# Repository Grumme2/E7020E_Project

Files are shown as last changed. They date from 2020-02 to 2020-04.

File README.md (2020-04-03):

# E7020E_Project

## Project Description

Our project purpose is to see whether a person is inside a perimeter or not. If the person is outside, a lamp on the board will light up.
This is going to be done with a MURATA board and a gps. We also have to implement a way to see the battery level. With the LoRa we are going to transmit the battery level, and if a user exits the perimeter, we are sending that users location.

## Higher grade

The group is aming for a higher grade than a basic pass. We are going to try to implement a charger of Lipo batteries, so that a user can charge a battery. 

## Components
* GPS: 410-237 - PmodGPS, Module UART, Digilent
* Battery charger: MCP73831T-2ACI/OT
* Battery: PIS-1218 - PiJuice Zero LiPo Battery, 500mAh, Pi Supply

https://docs.google.com/document/d/1sqJ3TY8bH1azIesI4otk2LLjVwCMFet3OU3TrjOT8jw/edit?usp=sharing

## Setup/Starting the project

### Prerequisites

In order to have the project working as intended you need to have the following things installed: 

* rustup 
* llvm-8.0
* llvm-config
* openocd
* gcc
* arm-none-eabi-gcc

### Building/running the project

First install rustup by following the instructions on https://rustup.rs/
After the installation you need to switch to the nightly toolchain rustup can use. First list the versions that are available:

`rustup toolchain list`

Then set the nightly toolchain as default:

`rustup default <nightly-toolchain>`

Then you need to install the following dependencies using rustup:

`rustup target add thumbv6m-none-eabi`

In order to start the project you first have to redirect to the **project_code** folder.

 `cd project_code`

 From that you need to make sure that you have a file called **stm32l0_dual_bank.cfg** in the **target** folder. If not, create a new file with that name that contains everything from https://github.com/ntfreak/openocd/blob/master/tcl/target/stm32l0_dual_bank.cfg

After this you may finally start **openocd**:

`openocd -f openocd.cfg`

Then open a new terminal window and redirect to the **project_code** directory, and from that you may run the program: 

`cargo run`

Now you should have a fully functional GPS-tracker on your hands!

## Team
* Anton Grahn - antgra-6@student.ltu.se
* Tom Hammarkvist - tomham-3@student.ltu.se
* Rickard Holmberg - richol-6@student.ltu.se

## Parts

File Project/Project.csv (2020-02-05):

Id | Designator | Package | Quantity | Designation | Supplier and ref
1 | U1 | CMWX1ZZABZ | 1 | CMWX1ZZABZ-078
2 | C1,C2 | C_0805_2012Metric_Pad1.15x1.40mm_HandSolder | 2 | 18p
3 | C3,C4,C5,C6,C7,C8,C9,C11,C12,C13 | C_0805_2012Metric_Pad1.15x1.40mm_HandSolder | 10 | 100n
4 | C10 | C_0805_2012Metric_Pad1.15x1.40mm_HandSolder | 1 | 10n
5 | C14,C15 | CP_Elec_6.3x4.9 | 2 | 10u
6 | J1 | PinHeader_1x05_P2.54mm_Vertical | 1 | Conn_01x05_Male
7 | J2 | USB_Mini-B_Wuerth_65100516121_Horizontal | 1 | USB_OTG
8 | R1,R2,R3 | R_0805_2012Metric_Pad1.15x1.40mm_HandSolder | 3 | 10k
9 | R4 | R_0805_2012Metric_Pad1.15x1.40mm_HandSolder | 1 | 3.3k
10 | U2 | SOT-223 | 1 | LM1117ADJ
11 | Y1 | Crystal_HC49-U_Vertical | 1 | 8Mhz

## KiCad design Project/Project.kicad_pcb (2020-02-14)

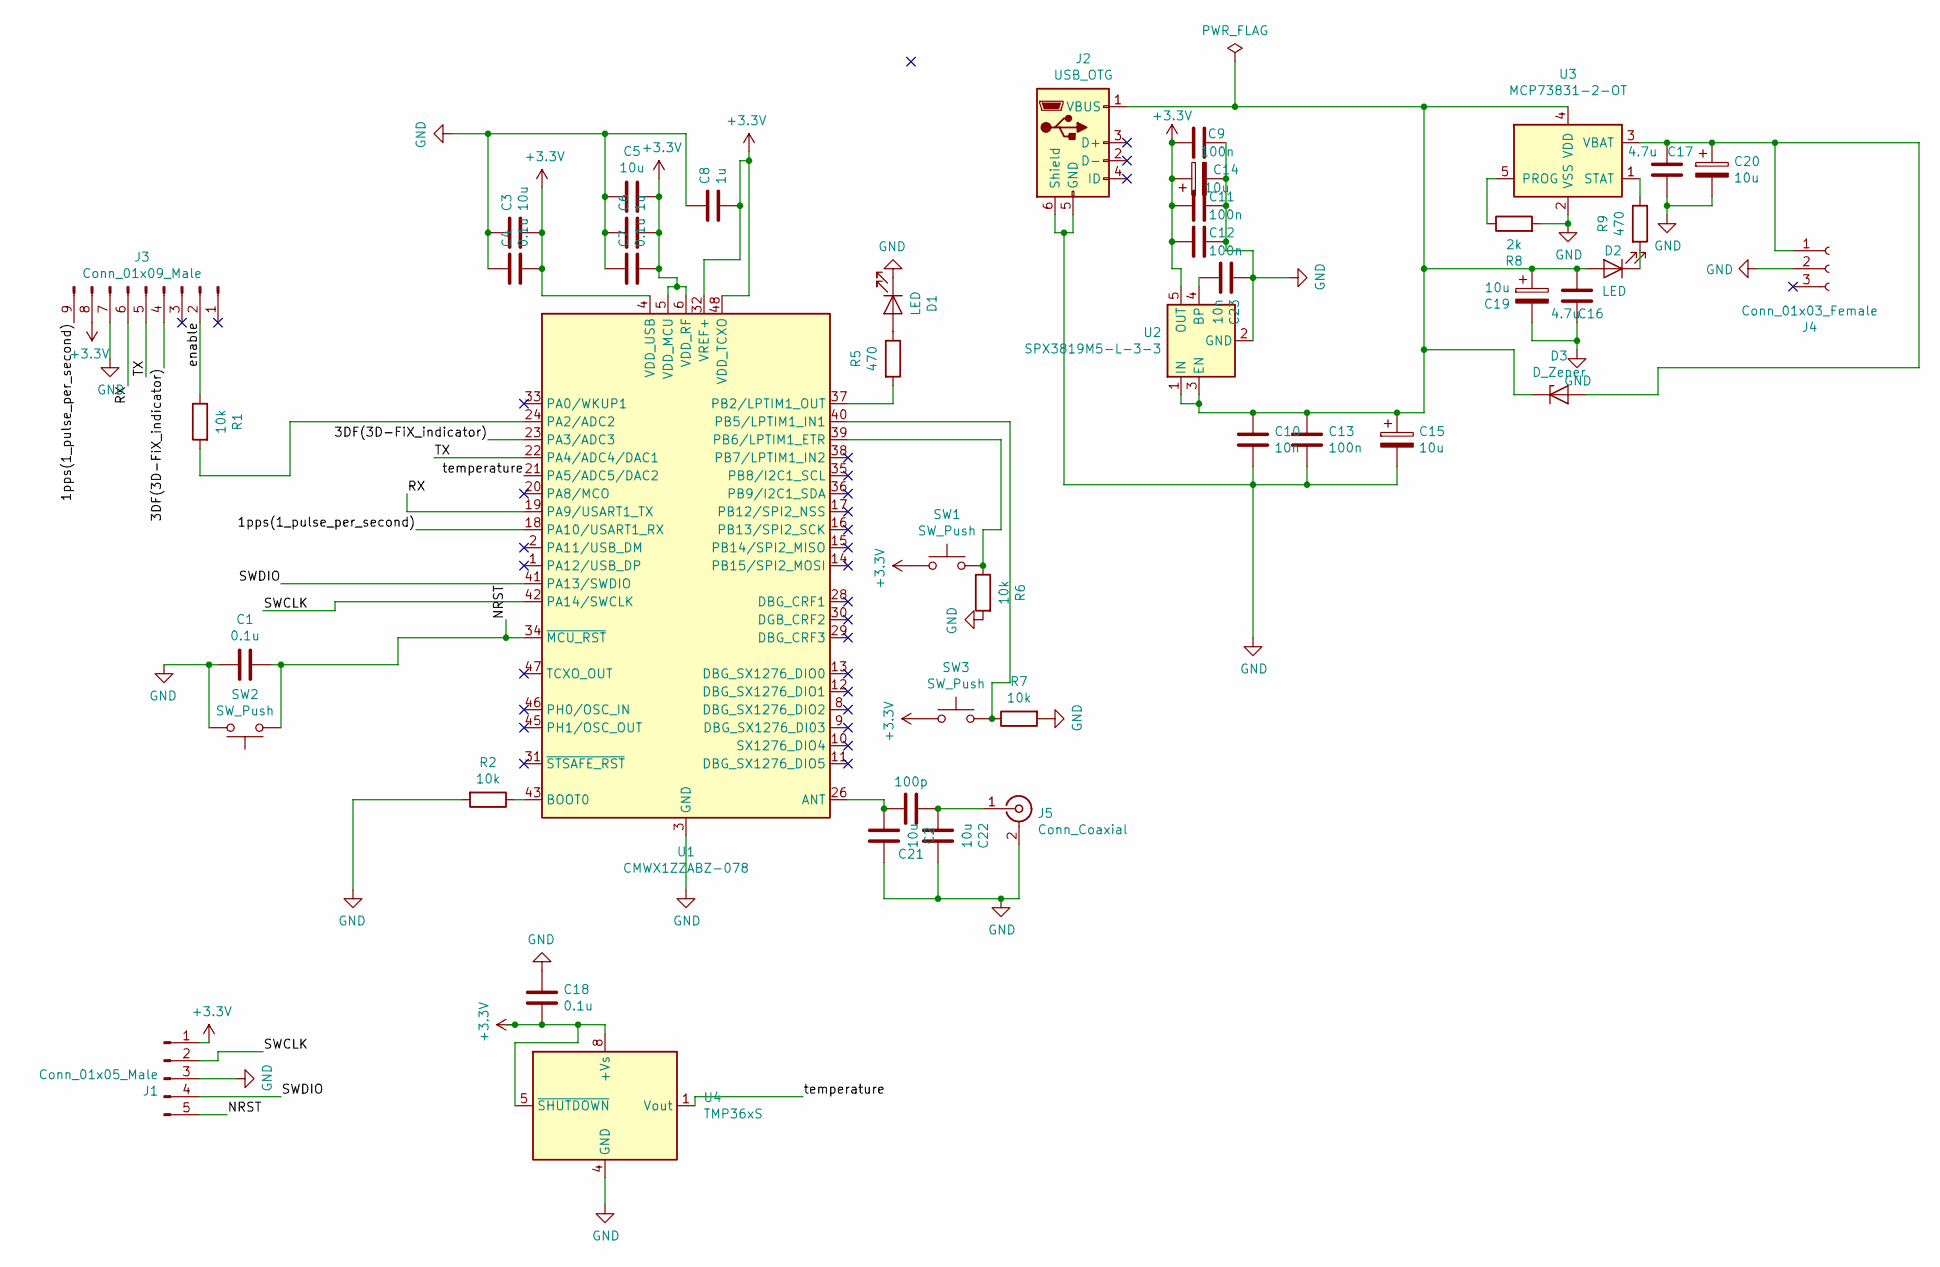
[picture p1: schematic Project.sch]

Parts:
C1, C4, C7, C18: 0.1u; C_0805_2012Metric_Pad1.15x1.40mm_HandSolder
C2, C3, C5, C22: 10u; C_0805_2012Metric_Pad1.15x1.40mm_HandSolder
C6, C8: 1u; C_0805_2012Metric_Pad1.15x1.40mm_HandSolder
C9, C11, C12, C13: 100n; C_0805_2012Metric_Pad1.15x1.40mm_HandSolder
C10, C23: 10n; C_0805_2012Metric_Pad1.15x1.40mm_HandSolder
C14, C15, C19, C20: 10u; CP_Elec_6.3x4.9
C16, C17: 4.7u; C_0805_2012Metric_Pad1.15x1.40mm_HandSolder
C21: 100p; C_0805_2012Metric_Pad1.15x1.40mm_HandSolder
D1, D2: LED; LED_0805_2012Metric_Pad1.15x1.40mm_HandSolder
D3: D_Zener; D_SMA_Handsoldering
J1: Conn_01x05_Male; PinHeader_1x05_P2.54mm_Vertical
J2: USB_OTG; USB_Micro-B_Wuerth_629105150521
J3: Conn_01x09_Male; PinHeader_1x09_P2.54mm_Vertical
J4: Conn_01x03_Female; JST_PH_B3B-PH-K_1x03_P2.00mm_Vertical
J5: Conn_Coaxial; U.FL_Molex_MCRF_73412-0110_Vertical
R1, R2, R6, R7: 10k; R_0805_2012Metric_Pad1.15x1.40mm_HandSolder
R5, R9: 470; R_0805_2012Metric_Pad1.15x1.40mm_HandSolder
R8: 2k; R_0805_2012Metric_Pad1.15x1.40mm_HandSolder
SW1, SW2, SW3: SW_Push; SW_Push_1P1T_NO_6x6mm_H9.5mm
U1: CMWX1ZZABZ-078; CMWX1ZZABZ_longer_pads
U2: SPX3819M5-L-3-3; SOT-23-5
U3: MCP73831-2-OT; SOT-23-5
U4: TMP36xS; SOIC-8_3.9x4.9mm_P1.27mm

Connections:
+3V3: C3.2, C4.2, C5.1, C6.2, C7.2, C8.2, C9.1, C11.2, C12.2, C14.1, C18.2, J1.1, J3.8, SW1.1, SW3.1, U1.4 (VDD_USB), U1.5 (VDD_MCU), U1.6 (VDD_RF), U1.32 (VREF+), U1.48 (VDD_TCXO), U2.5 (OUT), U4.5 (~SHUTDOWN), U4.8 (+Vs)
/1pps(1_pulse_per_second): J3.9, U1.18 (PA10/USART1_RX)
/3DF(3D-FiX_indicator): J3.4, U1.23 (PA3/ADC3)
/NRST: C1.1, J1.5, SW2.1, U1.34 (~MCU_RST)
/RX: J3.6, U1.19 (PA9/USART1_TX)
/SWCLK: J1.2, U1.42 (PA14/SWCLK)
/SWDIO: J1.4, U1.41 (PA13/SWDIO)
/TX: J3.5, U1.22 (PA4/ADC4/DAC1)
/VbAt: J3.3
/enable: J3.2, R1.1
/temperature: U1.21 (PA5/ADC5/DAC2), U4.1 (Vout)
GND: C1.2, C2.1, C3.1, C4.1, C5.2, C6.1, C7.1, C8.1, C9.2, C10.2, C11.1, C12.1, C13.2, C14.2, C15.2, C16.2, C17.1, C18.1, C19.2, C20.2, C22.1, C23.1, D1.1 (K), J1.3, J2.5 (GND), J2.6 (Shield), J3.7, J4.2, J5.2 (Ext), R2.2, R6.2, R7.2, R8.2, SW2.2, U1.3 (GND), U1.7 (GND), U1.25 (GND), U1.27 (GND), U1.44 (GND), U1.49 (GND), U1.50 (GND), U1.51 (GND), U1.52 (GND), U1.53 (GND), U1.54 (GND), U1.55 (GND), U1.56 (GND), U1.57 (GND), U2.2 (GND), U3.2 (VSS), U4.4 (GND)
unnamed: C2.2, C21.1, U1.26 (ANT)
unnamed: C10.1, C13.1, C15.1, C16.1, C19.1, D2.2 (A), D3.1 (K), J2.1 (VBUS), U2.1 (IN), U2.3 (EN), U3.4 (VDD)
unnamed: C17.2, C20.1, D3.2 (A), J4.1, U3.3 (VBAT)
unnamed: C21.2, C22.2, J5.1 (In)
unnamed: C23.2, U2.4 (BP)
unnamed: D1.2 (A), R5.1
unnamed: D2.1 (K), R9.2
unnamed: R1.2, U1.24 (PA2/ADC2)
unnamed: R2.1, U1.43 (BOOT0)
unnamed: R5.2, U1.37 (PB2/LPTIM1_OUT)
unnamed: R6.1, SW1.2, U1.39 (PB6/LPTIM1_ETR)
unnamed: R7.1, SW3.2, U1.40 (PB5/LPTIM1_IN1)
unnamed: R8.1, U3.5 (PROG)
unnamed: R9.1, U3.1 (STAT)

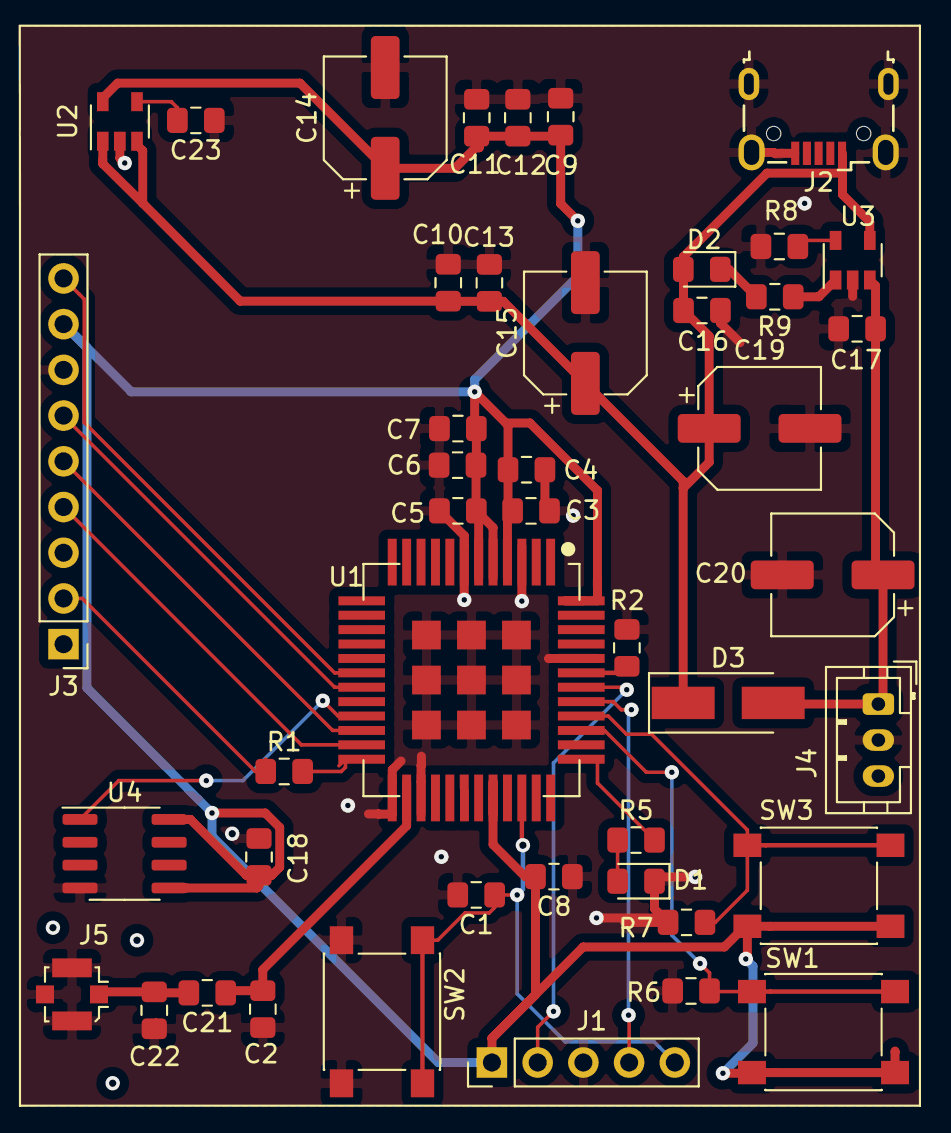
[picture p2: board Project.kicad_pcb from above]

Board: 2 copper layers, 45 parts (0 on the bottom side), 25 nets.

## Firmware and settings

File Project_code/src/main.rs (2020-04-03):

//#![cfg_attr(not(test), no_std)]
#![no_main]
#![no_std]
#![allow(deprecated)]

//mod longfi_bindings;

extern crate libm;

// 32-bit fixed point number, 16 bits for the integer part and 16 bits for
// the fractional part

extern crate panic_semihosting;

use hal::{
    adc::Adc,
    exti::TriggerEdge,
    exti::Interrupt,
    gpio::*,
    pac,
    prelude::*,
    rcc::Config,
    spi,
    syscfg,
    serial::{Config as serialConfig, Rx, Serial, Tx},
    stm32::usart1,
    stm32::{USART1},
    stm32::TIM2,
    delay::Delay,
    time::U32Ext,
    timer,
    timer::Timer,
};
use cortex_m_semihosting::{hprintln};
use cortex_m::peripheral::DWT;
use nb::block;
use rtfm::Mutex;
//use libm;
// use rtfm::{Exclusive, Mutex, app};
//use rtfm::cyccnt::{Instant, U32Ext as _};
// use longfi_bindings::AntennaSwitches;
// use longfi_device;
// use longfi_device::LongFi;
// use longfi_device::{ClientEvent, RfConfig, RfEvent};
use stm32l0xx_hal as hal;
// use communicator::{Message, Channel};
use heapless::consts::*;

#[rtfm::app(device = stm32l0xx_hal::pac, monotonic = rtfm::cyccnt::CYCCNT, peripherals = true)]
const APP: () = {
    struct Resources{
        INT: pac::EXTI,
        //static mut INT2: pac::EXTI = ();
        //static mut SX1276_DIO0: gpiob::PB4<Input<PullUp>> = ();
        DistanceButton: gpiob::PB5<Input<PullUp>>,
        PositionButton: gpiob::PB6<Input<PullUp>>,
        #[init([0; 512])]
        BUFFER: [u8; 512],
        // static mut LONGFI: LongFi = ();
        LED: gpiob::PB2<Output<PushPull>>,
        #[init(false)]
        STATE: bool,
        #[init(0)]
        COUNTER: u16,
        #[init(1)]
        COUNTER_TOGGLE: u16,
        TX: Tx<USART1>,
        RX: Rx<USART1>,
        TIMER_LED_INTERVAL: timer::Timer<pac::TIM2>,
        CURRENT_LON: f32,
        CURRENT_LAT: f32,
        START_LON: f32,
        START_LAT: f32,
        ADC: Adc,
        TEMP: gpioa::PA5<Analog>,
        #[init(false)]
        BLINK_ON: bool,
     //   ITM: ITM,
        //USART1: *const usart1::RegisterBlock,
    }
    #[init]
    fn init(cx: init::Context) -> init::LateResources {
        // Configure the clock.
        let mut rcc = cx.device.RCC.freeze(Config::hsi16());
        let mut syscfg = syscfg::SYSCFG::new(cx.device.SYSCFG, &mut rcc);
        
        // Acquire the GPIOB peripheral. This also enables the clock for GPIOB in
        // the RCC register.
        let gpioa = cx.device.GPIOA.split(&mut rcc);
        let gpiob = cx.device.GPIOB.split(&mut rcc);
        let gpioc = cx.device.GPIOC.split(&mut rcc);

    

        let exti = cx.device.EXTI;
        //let exti2 = device.EXTI;

        // Configure PB4 as input.
       // let sx1276_dio0 = gpiob.pb4.into_pull_up_input();
        let mut distancebutton = gpiob.pb5.into_pull_up_input();
        let mut positionbutton = gpiob.pb6.into_pull_up_input();
        let mut temp = gpioa.pa5.into_analog();
        let mut tim2 = timer::Timer::tim2(cx.device.TIM2, 1000.ms(), &mut rcc);
        let mut counter = 0;
        let mut current_lat = 65.199_f32;
        let mut current_lon = 2_f32;
        let mut start_lat = 65.200_f32;
        let mut start_lon = 2_f32;
        current_lat = current_lat;
        start_lat = start_lat;
        //let mut counter_toggle = 0;

        let mut rx = gpioa.pa10.into_pull_up_input();
        let mut tx = gpioa.pa9.into_push_pull_output();
        // Configure the external interrupt on the falling edge for the pin 2.

        let serial = Serial::usart1(
            cx.device.USART1,
            (tx, rx),
            serialConfig::default().baudrate(9_600.bps()), //    Is now 9600 (default, 8 bit data 1 stop)
            &mut rcc,   
        ).unwrap();

        let (tx, rx) = serial.split();

        exti.listen(
            &mut syscfg,
            distancebutton.port(),
            distancebutton.pin_number(),
            TriggerEdge::Rising,
        );
        exti.listen(
            &mut syscfg,
            positionbutton.port(),
            positionbutton.pin_number(),
            TriggerEdge::Rising,
        );

        let sck = gpiob.pb3;
        let miso = gpioa.pa6;
        let mosi = gpioa.pa7;
        //let nss = gpioa.pa15.into_push_pull_output();
        //longfi_bindings::set_spi_nss(nss);

        // Initialise the SPI peripheral.
        let mut _spi = cx.device
            .SPI1
            .spi((sck, miso, mosi), spi::MODE_0, 1_000_000.hz(), &mut rcc);

        let reset = gpioc.pc0.into_push_pull_output();

        let adc = cx.device.ADC.constrain(&mut rcc);

        // Configure PB5 as output.
        let mut led = gpiob.pb2.into_push_pull_output();
        tim2.listen();
       // led.set_high().ok();

       //let usart1 = serial::USART1::ptr();
        // Return the initialised resources.
        init::LateResources {
            INT: exti,
            //INT2: exti2,
            PositionButton: positionbutton,
            DistanceButton: distancebutton,
            LED: led,
            TX: tx,
            RX: rx,
            TIMER_LED_INTERVAL: tim2,
            START_LON: start_lon,
            START_LAT: start_lat,
            CURRENT_LON: current_lon,
            CURRENT_LAT: current_lat,
            TEMP: temp,
            ADC: adc,
            //COUNTER: counter,
        }
    }

    // #[task(capacity = 4, priority = 2, resources = [BUFFER, LED, STATE, COUNTER_1, COUNTER_2])]
    // fn radio_event(event: RfEvent) {
    //     // let longfi_radio = resources.LONGFI;
    //     // let client_event = longfi_radio.handle_event(event);
    //     match client_event {
    //         // ClientEvent::ClientEvent_TxDone => {
    //             // longfi_radio.receive();
    //         // }
    //          ClientEvent::ClientEvent_Rx => {
    //             // let rx_packet = longfi_radio.get_rx();

                
    //                 // let buf = unsafe {
    //                     // core::slice::from_raw_parts(rx_packet.buf, rx_packet.len as usize)
    //                 // };
    //                 //let message = Message::deserialize(buf);

    //                 // if let Some(message) = message {
    //                 //     // Let's assume we only have permission to use ID 2:
    //                 //     if message.id != 2 {
    //                 //         longfi_radio.set_buffer(resources.BUFFER);
    //                 //         longfi_radio.receive();
    //                 //         return;
    //                 //     }

    //                     let binary = application(
    //                         // message,
    //                         // resources.COUNTER_1,
    //                         // resources.COUNTER_2,
    //                         // resources.STATE,
    //                         resources.LED
    //                     );
    //                     // longfi_radio.send(&binary);
    //                 // }
                

    //             // longfi_radio.set_buffer(resources.BUFFER);
    //             // longfi_radio.receive();
    //         }
    //         ClientEvent::ClientEvent_None => {
                
    //             let binary = application(
    //                         // message,
    //                         // resources.COUNTER_1,
    //                         // resources.COUNTER_2,
    //                         // resources.STATE,
    //                 resources.LED
    //             );
    //         }
    //     }
    // }

    #[task(priority = 4, resources = [LED, COUNTER, TIMER_LED_INTERVAL, COUNTER_TOGGLE, BLINK_ON])]
    fn led_button_event(cx: led_button_event::Context) {
        //let temp: stm32l0xx_hal::gpio::gpiob::PB2<stm32l0xx_hal::gpio::Output<stm32l0xx_hal::gpio::PushPull>> = *cx.resources.LED;
        //led(cx.resources.LED, ledon);
        let mut led = cx.resources.LED;
        let mut counter = cx.resources.COUNTER;
        let mut counter_toggle = cx.resources.COUNTER_TOGGLE;
        let mut timer_led_interval = cx.resources.TIMER_LED_INTERVAL;
        let mut blink_on = cx.resources.BLINK_ON;
        blink_onTrue(blink_on);
        ledOff(led);
        counterReset(counter);
        counterToggle(counter_toggle);
        //hprintln!("counter {:?}", *counter_toggle);
        timer_led_interval.reset();
        timerListen(timer_led_interval);
        //ledBlink(cx.resources.LED, ledon, cx.resources.COUNTER);
    }

    #[task(binds = TIM2, priority = 3, resources = [LED, COUNTER, TIMER_LED_INTERVAL, COUNTER_TOGGLE, BLINK_ON])]
    fn led_timer_event(cx: led_timer_event::Context) {
        let mut led = cx.resources.LED;
        let mut counter = cx.resources.COUNTER;
        let mut counter_toggle = cx.resources.COUNTER_TOGGLE;
        let mut timer_led_interval = cx.resources.TIMER_LED_INTERVAL;
        let mut blink_on = cx.resources.BLINK_ON;
        let mut check = false;
        counter.lock(|counter| {
            counterPlusOne(counter);
            counter_toggle.lock(|counter_toggle| {
                if counterCheck(counter, counter_toggle) {
                    check = true;
                }  
            });
                //let counter = *cx.resources.COUNTER;;
            
        });
        led.lock(|led| {
            ledBlink(led);
            
        });
        timer_led_interval.lock(|timer_led_interval| {
            timer_led_interval.clear_irq();
            timer_led_interval.reset();
            if check {
                blink_on.lock(|blink_on| {
                    blink_onFalse(blink_on);
                });
                timerUnlisten(timer_led_interval);
            }
        });

    }

    #[task(priority = 1, resources = [CURRENT_LAT, CURRENT_LON, START_LAT, START_LON, LED, COUNTER_TOGGLE, BLINK_ON])]
    fn setpos_event(cx: setpos_event::Context, tu: (f32, f32, bool)) {
        let mut c_lon = cx.resources.CURRENT_LON;
        let mut c_lat = cx.resources.CURRENT_LAT;
        let mut s_lon = cx.resources.START_LON;
        let mut s_lat = cx.resources.START_LAT;
        let mut g_cu = cx.resources.COUNTER_TOGGLE;
        let mut led = cx.resources.LED;
        let mut blink_on = cx.resources.BLINK_ON;
        c_lon.lock(|c_lon| {
            c_lat.lock(|c_lat| {
                s_lon.lock(|s_lon| {
                    s_lat.lock(|s_lat| {
                        if tu.2 {
                            *c_lat = tu.0;
                            *c_lon = tu.1;
                        }
                        //hprintln!("C_lat {:?}, C_lon {:?} S_lat {:?} S_lon {:?}",c_lat, c_lon, s_lat, s_lon);
                        let distance = distance(c_lat, c_lon, s_lat, s_lon);
                        //hprintln!("distance {:?}",distance);
                        g_cu.lock(|g_cu| {
                            let temp_c = *g_cu as f32;
                            if distance*100_f32 > temp_c {
                                blink_on.lock(|blink_on| {
                                    if blink_onCheck(blink_on) == false {
                                        led.lock(|led| {
                                            ledOn(led);
                                        });
                                    }
                                });
                            } else {
                                blink_on.lock(|blink_on| {
                                    if blink_onCheck(blink_on) == false {
                                        led.lock(|led| {
                                            ledOff(led);
                                        });
                                    }
                                });
                            }
                        });
                    });
                });
            });
        });
    }
    // #[task(priority = 2, resources = [&LED])]
    // fn position_button_event(cx: position_button_event::Context){
        //let temp: stm32l0xx_hal::gpio::gpiob::PB2<stm32l0xx_hal::gpio::Output<stm32l0xx_hal::gpio::PushPull>> = *cx.resources.LED;
        // ledOn(cx.resources.LED);
    // }
    // #[task(priority = 4, resources = [&LED])]
    // fn distance_button_event(cx: distance_button_event::Context){
       // let temp: stm32l0xx_hal::gpio::gpiob::PB2<stm32l0xx_hal::gpio::Output<stm32l0xx_hal::gpio::PushPull>> = *cx.resources.LED;
        // ledOff(cx.resources.LED);
    // }
    // #[interrupt(priority = 1, resources = [SX1276_DIO0, INT], spawn = [radio_event])]
    // fn EXTI4_15() {
        // resources.INT.clear_irq(resources.SX1276_DIO0.pin_number());
        // spawn.radio_event(RfEvent::DIO0).unwrap();
        // }
    #[task(binds = EXTI4_15, priority = 2, resources = [DistanceButton, PositionButton, INT, CURRENT_LAT, CURRENT_LON, START_LAT, START_LON], spawn = [led_button_event])]
    fn EXTI4_15(c: EXTI4_15::Context) {
        
       // let mut distancebutton: gpiob::PB5<Input<PullUp>> = c.resources.DistanceButton;
        let res = c.resources.DistanceButton.is_high();
        match res {
            core::result::Result::Ok(v) => {
                if v==true {
                    //hprintln!("Hello!_testif").unwrap();
                    c.resources.INT.clear_irq(c.resources.DistanceButton.pin_number());
                    c.spawn.led_button_event().unwrap();
                }
            }
            _ => {}
        }
        let res = c.resources.PositionButton.is_high();
        match res {
            core::result::Result::Ok(v) => {
                // if v==true {
                //     //hprintln!("Hello!_testelse").unwrap();
                //     c.resources.INT.clear_irq(c.resources.PositionButton.pin_number());
                //     *c.resources.START_LAT = *c.resources.CURRENT_LAT;
                //     *c.resources.START_LON = *c.resources.CURRENT_LON;
                // }
                if v==true {
                    //hprintln!("Hello!_testelse").unwrap();
                    c.resources.INT.clear_irq(c.resources.PositionButton.pin_number());
                    if *c.resources.START_LAT == 65.2_f32 {
                        *c.resources.START_LAT = 65.199_f32;
                    } else {
                        *c.resources.START_LAT = 65.2_f32;
                    }
                    
                }
            }
            _ => {}
        }
    }

     #[idle(resources = [RX, TX, TEMP, ADC, BLINK_ON], spawn = [setpos_event]) ]
    fn idle(cx: idle::Context) -> ! {
        let rx = cx.resources.RX;
        let tx = cx.resources.TX;
        // let mut c_lon = cx.resources.CURRENT_LAT;
        // let mut c_lat = cx.resources.CURRENT_LON;
        // let mut s_lon = cx.resources.START_LON;
        // let mut s_lat = cx.resources.START_LAT;
        // let mut g_cu = cx.resources.COUNTER_TOGGLE;
        // let mut led = cx.resources.LED;
        // let mut blink_on = cx.resources.BLINK_ON;
        let mut adc = cx.resources.ADC;
        let mut temp = cx.resources.TEMP;

        gpsInit(tx);
        
        let mut counter: usize = 100;
        let mut buf: [u8; 82] = [0; 82];
        loop {
            //hprintln!("test");
            match block!(rx.read()) {
                Ok(byte) => {
                    if counter < 82usize{            //Build array
                       // hprintln!("check if counter");
                        buf[counter] = byte;
                        counter += 1;
                        if byte == 10 && buf[counter-2] == 13 {//checks for end of message characters <CR><LR>
                            let mut val: u16 = adc.read(temp).unwrap();
                            //hprintln!("temp {:?}", val);
                            //hprintln!("end of message c {:?}", counter);
                            counter =  100;
                            let tu = parsenmeabuf(buf); 
                            cx.spawn.setpos_event(tu).unwrap();
                        }
                    } else if byte == 36 {      //checks for start character $
                        counter =  0;
                        //hprintln!("startchar {:?}", counter);
                        buf[counter] = byte;
                    } else {
                        continue;
                    }
                    //hprintln!("{:?}", byte);
                    //tx.write(byte).unwrap();
                }
                Err(err) => {
                    hprintln!("Error {:?}", err);
                }
            }   
        }

    }



    // #[task(priority = 2, resources = [LED])]
    // fn led_button_event(cx: led_button_event::Context, ledon: bool){
        ////let temp: stm32l0xx_hal::gpio::gpiob::PB2<stm32l0xx_hal::gpio::Output<stm32l0xx_hal::gpio::PushPull>> = *cx.resources.LED;
        // led(cx.resources.LED, ledon);
    // }

    //#[task(binds = EXTI4_15, priority = 1, resources = [DistanceButton, PositionButton, INT], spawn = [led_button_event])]
    // fn EXTI4_15(c: EXTI4_15::Context) {
        // 
      //// let mut distancebutton: gpiob::PB5<Input<PullUp>> = c.resources.DistanceButton;
        // let res = c.resources.DistanceButton.is_high();
        // match res {
            // core::result::Result::Ok(v) => {
                // if v==true {
                    // hprintln!("Hello!_testif").unwrap();
                    // c.resources.INT.clear_irq(c.resources.DistanceButton.pin_number());
                    // c.spawn.led_button_event(false).unwrap();
                // } else {
                    // hprintln!("Hello!_testelse").unwrap();
                    // c.resources.INT.clear_irq(c.resources.PositionButton.pin_number());
                    // c.spawn.led_button_event(true).unwrap();
                // }
            // },
            // _ => {
// 
            // }
        // }
   // }

    // #[task(binds = USART1, priority = 1, resources = [USART1, INT], spawn = [position_button_event])]
    // fn usart(cx: usart::Context){
        // cx.resources.INT.clear_irq(c.resources.USART1.ptr();
        // cx.spawn.usart_event().unwrap();
// 
    // }
    
    // #[task(priority = 2, resources = [USART1])]
    // fn usart_button_event(cx: usart_button_event::Context){
        // 
    // }

    // Interrupt handlers used to dispatch software tasks
    extern "C" {
        fn USART4_USART5();
        fn LPTIM1();
        fn I2C2();
    }
};

fn printbuf(buf: [u8; 82]) {
    for x in 0..81 {
        hprintln!("{:?}", buf[x] as char);
    }
}


fn ledOn(led: &mut gpiob::PB2<Output<PushPull>>) {
    led.set_high().ok();
}

fn ledOff(led: &mut gpiob::PB2<Output<PushPull>>) {
    led.set_low().ok();
}

fn led(led: &mut gpiob::PB2<Output<PushPull>>, turnon: bool,) {
   
    if turnon==true {
        led.set_high().ok();
    } else {
        led.set_low().ok();
    }

}

fn ledBlink(led: &mut gpiob::PB2<Output<PushPull>>){
    let res = led.is_low();
    match res {
        core::result::Result::Ok(v) => {
            if v==true {
                led.set_high().ok();
                
            } else {
                led.set_low().ok();
            }
        }
        _ => {}
    }
}

fn blink_onTrue(blink_on: &mut bool) { *blink_on = true; }

fn blink_onFalse(blink_on: &mut bool) { *blink_on = false; }

fn blink_onCheck(blink_on: &mut bool) -> bool { return *blink_on; }

fn counterPlusOne(counter: &mut u16) { *counter += 1u16; }

fn counterReset(counter: &mut u16) { *counter = 0; }

fn counterCheck(counter: &mut u16, check: &mut u16) -> bool {
    let mut temp = *check;
    if *counter >= (2u16*temp) {
        return true;
    } else {
        return false;
    }
}

fn counterToggle(counter: &mut u16) {
    if *counter == 1 {
        *counter = 2u16;
    } else if *counter == 2 {
        *counter = 3u16;
    } else {
        *counter = 1u16;
    }
}

fn timerListen(timer: &mut timer::Timer<pac::TIM2>) {
    timer.listen();
}

fn timerUnlisten(timer: &mut timer::Timer<pac::TIM2>) {
    timer.unlisten();
}

fn distance(lat1_p: &mut f32,lon1_p: &mut f32,lat2_p: &mut f32,lon2_p: &mut f32) -> f32 {
    let lat1 = *lat1_p;
    let lon1 = *lon1_p;
    let lat2 = *lat2_p;
    let lon2 = *lon2_p;
    let R = 6371_f32; // Radius of the earth in km
    let dLat = deg2rad(lat2-lat1);  // deg2rad below
    let dLon = deg2rad(lon2-lon1); 
    let a = 
        sinDeg(rad2deg(dLat)/2_f32) * sinDeg(rad2deg(dLat)/2_f32) +
        cos(deg2rad(lat1)) * cos(deg2rad(lat2)) * 
        sinDeg(rad2deg(dLon)/2_f32) * sinDeg(rad2deg(dLon)/2_f32);
    let c = 2_f32 * atan2(sqrt(a), sqrt(1_f32 - a)); 
    let d = R * c; // Distance in km
    return d;
  }
  
fn rad2deg(rad: f32) -> f32{
    return (rad* 180_f32)/pi();
}
fn deg2rad(deg: f32) -> f32 {
    let t2 = 180_f32;
    return deg * (pi()/t2);
}

fn sinDeg(x: f32) -> f32 {
    let t1 = 40500_f32;
    let t2 = 180_f32;
    let t3 = 4_f32;
    return (t3*x*(t2-x))/(t1-x*(t2-x));
}

fn cos(y: f32) -> f32 {
    let t2 = 4_f32;
    return ((pi()*pi() - t2*(y*y))/(pi()*pi() + (y*y)));
}

fn atan2(y: f32, x: f32) -> f32 {
    if x > 0_f32 {
        return atan(y/x);
    } else if y > 0_f32 {
        return pi()/2_f32 - atan(x/y);
    } else if y < 0_f32 {
        (-1_f32*pi())/2_f32 - atan(x/y);
    } else if x < 0_f32 {
        atan(x/y) + pi();
    }
    return 0_f32;
}

fn atan(x: f32) -> f32 {
    let mut c = 0.28125_f32;
    return x/(1_f32+c*x*x);
}

fn sqrt(x: f32) -> f32 {
    return libm::powf(x, 0.5_f32);
}

fn pi() -> f32 {
    return 3.14_f32;
    //return I18F14(314_f32).unwrap() / I18F14(100_f32).unwrap();
}
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

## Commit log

2020-02-05 some components added
    [Project.csv, Project.kicad_pcb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]
2020-02-05 placed some more components
    [Project.sch]
2020-02-06 Conn added for battery and some connections
    [Project.sch]
2020-02-07 some more components and footprints
    [Project.sch]
2020-02-07 more components and footprints
    [Project.sch]
2020-02-10 almost all footprints and schematic done
    [Project.sch]
2020-02-10 some placements put
    [Project.kicad_pcb, Project.sch]
2020-02-10 placed all components
    [Project.kicad_pcb, Project.sch]
2020-02-10 started routing
    [Project.kicad_pcb]
2020-02-11 some more routing
    [Project.kicad_pcb]
2020-02-11 all routes done and copperlayer
    [Project.kicad_pcb, Project.sch]
2020-02-11 changed some fottprints that where wrong
    [Project.kicad_pcb, Project.sch]
2020-02-12 updated schematic
    [Project.sch]
2020-02-12 final design??
    [Project.kicad_pcb]
2020-02-13 final design probably
    [Project.kicad_pcb, Project.sch]
2020-02-13 gerberfiles done
    [Proejct-PTH.drl, Project-B_Cu.gbr, Project-B_Mask.gbr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]
2020-02-14 final design
    [Project.kicad_pcb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]
2020-03-12 Button now working with LED
2020-03-12 can turn on and off led
2020-03-31 cont with serial, rx and tx should be correct ports
    [main.rs]
